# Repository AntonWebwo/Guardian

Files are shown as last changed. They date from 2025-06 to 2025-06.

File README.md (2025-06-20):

GUARDIAN

# Guardian - Пожарно-охранная система на Arduino

## Описание

Система Guardian – это пожарно-охранная система на базе Arduino, предназначенная для мониторинга состояния помещения и оповещения о возникновении нештатных ситуаций, таких как:

*   Открытие двери
*   Обнаружение движения
*   Задымление
*   Превышение уровня воды
*   Изменение температуры и влажности

## Функциональность

*   Поддержка до 3 зон (помещений)
*   Контроль открытия двери (геркон)
*   Обнаружение движения (PIR-датчики)
*   Обнаружение задымления (датчики дыма)
*   Контроль уровня воды (датчик уровня воды)
*   Мониторинг температуры и влажности (DHT22)
*   Постановка/снятие с охраны с помощью keypad
*   SMS-оповещения через GSM-модуль
*   Звуковые оповещения через DFPlayer Mini
*   Световая индикация режимов работы (светодиоды)
*   Управление реле (сирена, свет)
*   Настройка параметров через Serial Monitor

#### Система состоит из двух Arduino:

*  **Основная Arduino**: 
   Обрабатывает данные с вспомогательной Arduino, управляет логикой работы системы (постановка/снятие с охраны, сирена, реле), взаимодействует с пользователем через LCD-дисплей и keypad, отправляет SMS-оповещения через GSM-модуль и воспроизводит звуковые оповещения через DFPlayer Mini.

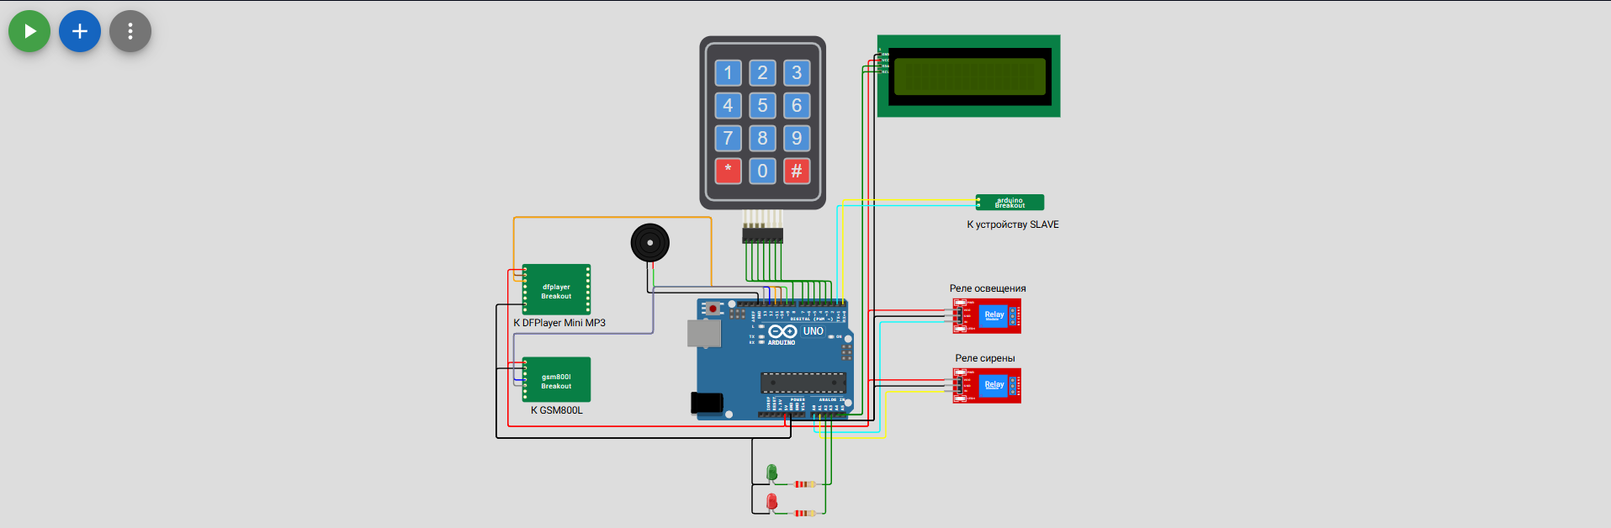
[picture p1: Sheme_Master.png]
Схема головного устройства


*  **Вспомогательная Arduino**: Собирает данные с датчиков (геркон, датчики дыма, датчики движения, датчик температуры и влажности DHT22, датчик уровня воды) и передает их на основную Arduino по последовательному порту.

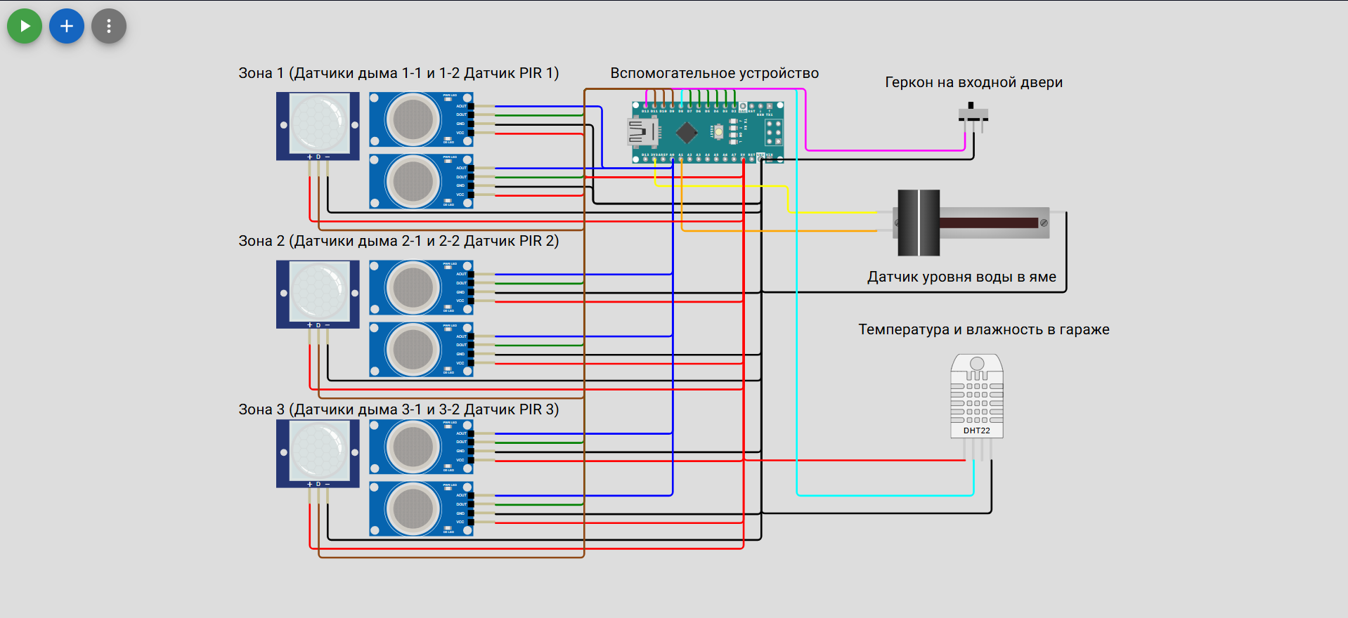
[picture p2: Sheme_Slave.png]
Схема вспомогательного устройства


## Схема подключения

### Основная Arduino
    
    +-------------------------+---------------------+
    | Компонент               | Пин Arduino         |
    +-------------------------+---------------------+
    | LCD-дисплей (SDA)       | A4                  |
    | LCD-дисплей (SCL)       | A5                  |
    | Keypad                  | 2, 3, 4, 5, 6, 7, 8 |
    | Реле света              | A0                  |
    | Реле сирены             | A1                  |
    | Красный светодиод       | A2                  |
    | Зеленый светодиод       | A3                  |
    | Буззер                  | 9                   |
    | DFPlayer Mini (RX)      | 11                  |
    | DFPlayer Mini (TX)      | 10                  |
    | GSM-модуль (RX)         | 13                  |
    | GSM-модуль (TX)         | 12                  |
    | Serial (Вспом. Arduino) | (RX, TX)            |
    +-------------------------+---------------------+

### Вспомогательная Arduino

    +---------------------------------------+-----------------------+
    | Компонент                             | Пин Arduino           |
    +---------------------------------------+-----------------------+
    | Датчик температуры/влажности (DHT22)  | 8                     |
    | Датчики дыма                          | A0 + 2, 3, 4, 5, 6, 7 |
    | Датчики движения (PIR)                | 9, 10, 11             |
    | Геркон                                | 12                    |
    | Датчик уровня воды                    | A1                    |
    | Serial (Основ. Arduino)               | (RX, TX)              |
    +---------------------------------------+-----------------------+

#### Протоколы и взаимодействие

1. **I2C**: Используется для связи основной Arduino с LCD-дисплеем. Адрес дисплея по умолчанию – 0x27.

2. **Последовательный порт (Serial)**:

   * Основная Arduino принимает данные от вспомогательной Arduino в следующем формате (Hex String):

            FF[GerconState][Sensor1][Sensor2][Sensor3][Sensor4][Sensor5][Sensor6][Motion1][Motion2][Motion3][TemperatureSign][Temperature][Humidity][WaterLevel]FF

      * FF: Start and End Byte
      * GerconState: 01 - дверь открыта, 00 - дверь закрыта
      * Sensor1-6: 01 - задымление, 00 - норма
      * Motion1-3: 01 - движение, 00 - нет движения
      * TemperatureSign: 00 - отрицательная температура, 01 - положительная температура
      * Temperature: Температура в градусах Цельсия (Hex)
      * Humidity: Влажность в процентах (Hex)
      * WaterLevel: 01 - высокий уровень воды, 00 - норма
      
        Примеры пакетов от вспомогательной Arduino:

      * `FF00000000000000000000010d4000FF` - Дверь закрыта. Дыма нет. Движения нет. Не затапливает. Температура 13.0°C. Влажность 64.5%.
      * `FF00000000000000000100010d4000FF` - Дверь закрыта. Дыма нет. Сработал датчик движения. Не затапливает. Температура 13.0°C. Влажность 64.5%.
      * `FF00000100000000000000010d4000FF` - Дверь закрыта. Сработал 1 датчик дыма. Движения нет. Не затапливает. Температура 13.0°C. Влажность 64.5%.
      * `FF00010100000000000000010d4000FF` - Дверь закрыта. Сработали 2 датчика дыма. Движения нет. Не затапливает. Температура 13.0°C. Влажность 64.5%.
      * `FF01000000000000000000010d4000FF` - Дверь открыта. Дыма нет. Движения нет. Не затапливает. Температура 13.0°C. Влажность 64.5%.
      * `FF00000000000000000000010d4001FF` - Дверь закрыта. Дыма нет. Движения нет. Затапливает. Температура 13.0°C. Влажность 64.5%.

    * Основная Arduino отправляет команды конфигурации на основную Arduino в формате:

    	* SET[variable]=[value] - установить значение переменной
    	* GET[variable] - получить значение переменной

3. **GSM (Serial)**: Основная Arduino использует AT-команды для отправки SMS-оповещений через GSM-модуль.
4. **DFPlayer Mini (Serial)**: Основная Arduino использует библиотеку `DFPlayer_Mini_Mp3.h` для воспроизведения звуковых оповещений.

#### Конфигурация

Параметры системы хранятся в EEPROM основной Arduino. Их можно изменить через Serial Monitor, отправляя команды `SET`.

   * `secretCode`: Код для снятия/постановки на охрану (4 цифры). По умолчанию "0000".
   * `phoneOperator`: Номер телефона оператора для отправки SMS (11 цифр). По умолчанию "89000000000".
   * `delay_lock`: Задержка перед постановкой на охрану (мс). По умолчанию 2500.
   * `delay_unlock`: Задержка перед снятием с охраны (мс). По умолчанию 500.
   * `delay_pass`: Задержка после ввода неверного пароля (мс). По умолчанию 1000.
   * `pass_timeout`: Время ожидания ввода пароля после открытия двери (мс). По умолчанию 30000.
   * `delay_siren`: Время работы сирены (мс). По умолчанию 30000.

Пример:

   * `SET secretCode=1234`
   * `SET phoneOperator=89123456789`
   * `GET info` - выводит текущие настройки в Serial Monitor
   * ~~`GET eeprom` - выводит дамп EEPROM в Serial Monitor~~

#### Логика работы

1. **Постановка на охрану**:
	* Пользователь нажимает кнопку # на клавиатуре.
	* Воспроизводится звуковое оповещение "Взятие под охрану. Покиньте объект!".
	* Моргает зеленый светодиод.
	* Идёт обратный отсчет **delay_lock**.
	* По окончанию **delay_lock** гаснет свет и подсветка на дисплее.
	* Воспроизводится звуковое оповещение "Объект установлен под охрану!".
	* Загорается красный светодиод.
	* Прибор переходит в режим охраны.
2. **Снятие с охраны**:
	* Пользователь открывает дверь (срабатывает геркон).
	* Включается свет и подсветка на дисплее.
	* Воспроизводится звуковое оповещение "Внимание! Дверь открыта. Введите пароль!".
	* Идёт обратный отсчет **pass_timeout**.
	* Если код верен, система снимается с охраны через **delay_unlock**.
		* Включается зеленый светодиод, выключается красный.
		* Воспроизводится звуковое оповещение "Внимание! Объект снят с охраны!".
	* Если код верен неправильный:
		* Продолжается отсчет **pass_timeout**.
		* Воспроизводится звуковое оповещение "Неправильный пароль! Повторите попытку!".
		* Идёт обратный отсчет **delay_pass**.
	* Если истекло время ввода правильного пароля:
		* Выключается свет и посветка на дисплее.
		* Воспроизводится звуковое оповещение "Тревога! Проникновение на объект!".
		* Включается сирена.
		* Идёт отправка SMS о событии.
3. **Тревога**:
	* При срабатывании датчиков (движение, задымление, превышение уровня воды) система отправляет SMS-оповещение на номер телефона оператора.
	* Включается сирена.
	* Воспроизводится соответствующее звуковое оповещение.
4. **Изменение код**а:
	* В режиме снятия с охраны пользователь нажимает кнопку "*".
	* Система предлагает ввести новый код и подтвердить его.
	* Если коды совпадают, новый код сохраняется в EEPROM.

#### Необходимые библиотеки

* Wire.h
* LiquidCrystal_I2C.h
* Keypad.h
* EEPROM.h
* SoftwareSerial.h
* DFPlayer_Mini_Mp3.h
* dht.h

#### Голосовое уведомление

Файлы Mp3 необходимо поместить в папку mp3 на sd карте в DFPlayer Mini. Библиотека *DFPlayer Mini Mp3* будет автоматически вызывать и проигрывать нужный трек при событиях.

#### Компоненты

* Прибор

    * Arduino UNO
	* Arduino Nano
	* Плата расширения IO Shield для Arduino Nano
	* Корпус пластиковый 120х100х40 мм для конструирования РЭА
	* Источник бесперебойного питания 12 В-2 А
	* Дисплей LCD1602C с I2C
	* [Накладка на дисплей](Models/Display_panel.stl)
	* Матричная клавиатура 3х4 механическая
	* Зуммер
	* Светодиодный модуль 0.23 Вт, Красный/Зелёный 
	* Модуль реле Ардуино, 2 канала, 220В 10А
	* Динамик YD103-71 6W 8ohm
	* Аудио модуль (MP3-плеер) DFPlayer mini
	* Модуль GPRS GSM SIM800l + антена

* Датчики и комплектующие

    * Датчик широкого спектра газов MQ-2 Arduino (6 ШТ)
	* [Корпус (низ) для MQ-2](Models/MQ2-Bottom-02.stl)
	* [Корпус (верх) для MQ-2](Models/MQ2-Top-02.stl)
    * Инфракрасный датчик движения HC-SR501 для Arduino (3 ШТ)
	* [Корпус для HC-SR501](Models/PIR45_angular.stl)
	* Проводной магнитоконтактный датчик (геркон) двери (1 ШТ)
	* Датчик уровня воды Ардуино (1 ШТ)
	* Цифровой датчик температуры и влажности DHT22 (AM2302) (1 ШТ)
	* Проводная свето-звуковая сирена к охранной сигнализации
	* Светодиодный модуль 0.23 Вт, Красный/Зелёный 

#### Информация

Попробовать в эмуляторе можно по ссылкам:

[Головное устройство](https://wokwi.com/projects/432747694750118913)
[Вспомогательное устройство](https://wokwi.com/projects/432639970081871873)

## Автор

[Антон Виноградов](https://t.me/vinantole)

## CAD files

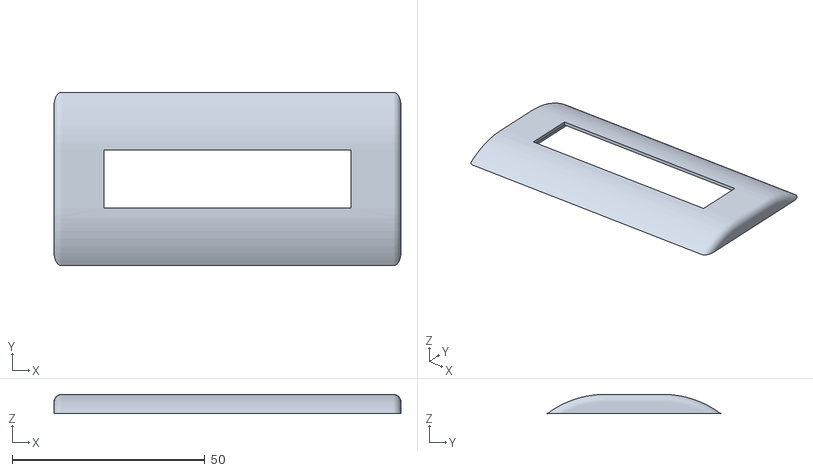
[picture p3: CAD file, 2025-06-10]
Models/Display_panel.stl
90.0 x 45.0 x 5.00

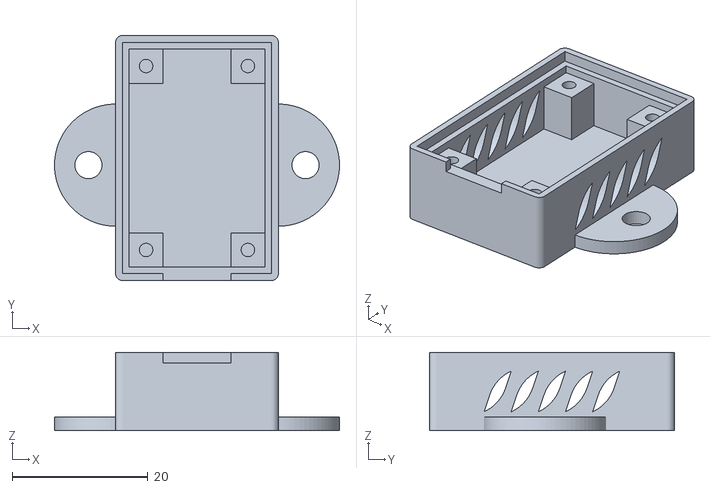
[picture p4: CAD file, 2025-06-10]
Models/MQ2-Bottom-02.stl
42.0 x 36.1 x 11.6

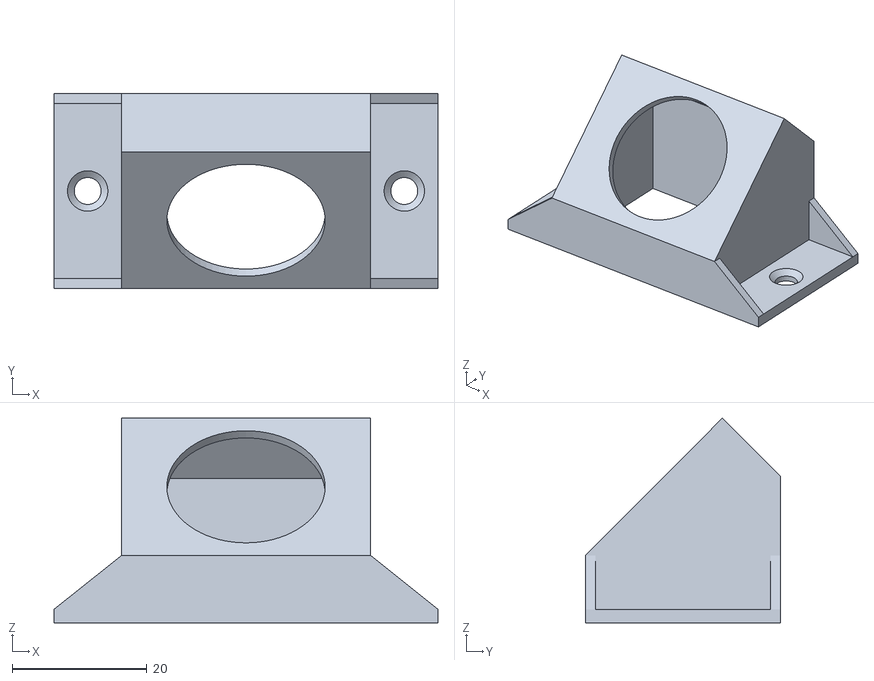
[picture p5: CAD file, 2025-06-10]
Models/PIR45_angular.stl
57.0 x 29.0 x 30.4

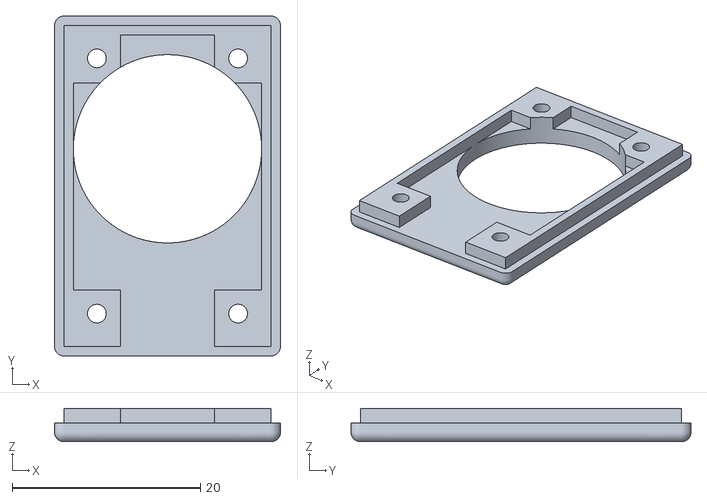
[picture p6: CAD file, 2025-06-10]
Models/MQ2-Top-02.stl
24.0 x 36.1 x 3.55

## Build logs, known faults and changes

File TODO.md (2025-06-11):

### Далее добавить

* Опрос состояния через SMS
* Пожарные события:
  * При сработке 1 датчика дыма: Предупреждение и SMS о событии.
  * При сработке 2 датчиков в одной зоне: Событие "Пожар" и SMS о событии.
* Имена зон в памяти устройства и отображение их при собвтии в SMS и на экране, например: *lobby -> motion detect!*
* Поддержка дополнительных вспомогательных устройств (Поддержка более 3 зон).
* Снятие / постановка при помощи RFID-модуля.
* Снятие / постановка через SMS.
* WEB приложение.

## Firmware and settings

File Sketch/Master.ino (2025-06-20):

#include <Wire.h>
#include <LiquidCrystal_I2C.h>
#include <Keypad.h>
#include <EEPROM.h>
#include <SoftwareSerial.h>
#include <DFPlayer_Mini_Mp3.h>

String version = "1.2.4"; // Версия прошивки

LiquidCrystal_I2C lcd(0x27, 16, 2);
uint8_t iconLocked[8] = {0x0e, 0x11, 0x11, 0x1f, 0x1b, 0x1b, 0x1f};
uint8_t iconUnlocked[8] = {0x0e, 0x10, 0x10, 0x1f, 0x1b, 0x1b, 0x1f};

char keys[4][3] = { { '1', '2', '3' }, { '4', '5', '6' }, { '7', '8', '9' }, { '*', '0', '#' } };
uint8_t colPins[3] = { 4, 3, 2 };
uint8_t rowPins[4] = { 8, 7, 6, 5 };
Keypad keypad = Keypad(makeKeymap(keys), rowPins, colPins, 4, 3);

char secretCode[5] = "";
char phoneOperator[12] = "";
int delay_lock, delay_unlock, delay_pass, pass_timeout, delay_siren;

char sensors[6][3];
char motion[3][3];
char gercoState[3];
char waterLevel[3];
int humidity, temperature;

int lastHumidity = -1;
int lastTemperature = -1;

bool Locked = true;
char enterCode[5] = "";
char newCode[5] = "";
char confirmCode[5] = "";

bool isDisplayed = false;
bool isNewCode = false;

unsigned long sirenStartTime = 0;
unsigned long lightStartTime = 0;

bool sirenActive = false;
bool lightActive = false;
bool alarmActive = false;

unsigned long alarmStartTime = 0;
const unsigned long alarmInterval = 500;
const unsigned long soundDuration = 300;

unsigned long lastWaterLevelAlertTime = 0;
const unsigned long waterLevelAlertInterval = 30 * 60 * 1000;

SoftwareSerial dfPlayerSerial(11, 10);
SoftwareSerial sim800l(13, 12);

void setup() {
    Serial.begin(115200);
    dfPlayerSerial.begin(9600);
    mp3_set_serial (dfPlayerSerial);
    mp3_set_volume (25);
    sim800l.begin(9600);
    sim800l.println("AT+CMGF=1");
    sim800l.println("AT+CNMI=2,2,0,0,0");
    loadSettings();
    lcd.begin(16, 2);
    lcd.createChar(1, iconLocked);
    lcd.createChar(2, iconUnlocked);
    lcd.noBacklight();
    pinMode(A2, OUTPUT);
    pinMode(A3, OUTPUT);
    pinMode(A0, OUTPUT);
    pinMode(A1, OUTPUT);
    pinMode(9, OUTPUT);
    digitalWrite(A2, HIGH);
    digitalWrite(A3, LOW);
    digitalWrite(A0, LOW);
    digitalWrite(A1, LOW);
    showStartupMessage();
}

void loop() {
    static unsigned long previousMillis = 0;
    const long interval = 100;

    unsigned long currentMillis = millis();
    if (currentMillis - previousMillis >= interval) {
        previousMillis = currentMillis;
        getSerialData();
        if (Locked) {
            checkSiren();
            monitorAlarmSystem();
            safeLockedLogic();
        } else {
            lcd.backlight();
            safeUnlockedLogic();
        }
        checkAlarm();
    }
}

void loadSettings() {
    bool settingsChanged = false;

    EEPROM.get(0, secretCode);
    EEPROM.get(16, phoneOperator);
    EEPROM.get(32, delay_lock);
    EEPROM.get(48, delay_unlock);
    EEPROM.get(64, delay_pass);
    EEPROM.get(80, pass_timeout);
    EEPROM.get(96, delay_siren);

    if (strlen(secretCode) != 4 || strspn(secretCode, "0123456789") != 4) {
        strcpy(secretCode, "0000");
        writeStringToEEPROM(0, secretCode);
        settingsChanged = true;
    }

    if (strlen(phoneOperator) != 11 || strspn(phoneOperator, "0123456789") != 11) {
        strcpy(phoneOperator, "89000000000");
        writeStringToEEPROM(16, phoneOperator);
        settingsChanged = true;
    }

    if (delay_lock <= 0) {
        delay_lock = 2500;
        EEPROM.put(32, delay_lock);
        settingsChanged = true;
    }

    if (delay_unlock <= 0) {
        delay_unlock = 500;
        EEPROM.put(48, delay_unlock);
        settingsChanged = true;
    }

    if (delay_pass <= 0) {
        delay_pass = 1000;
        EEPROM.put(64, delay_pass);
        settingsChanged = true;
    }

    if (pass_timeout <= 0) {
        pass_timeout = 30000;
        EEPROM.put(80, pass_timeout);
        settingsChanged = true;
    }

    if (delay_siren <= 0) {
        delay_siren = 30000;
        EEPROM.put(96, delay_siren);
        settingsChanged = true;
    }

    if (settingsChanged) {
        handleGetCommand("GET info");
    }
}


void writeStringToEEPROM(int address, const char* str) {
    for (int i = 0; i < strlen(str); i++) {
        EEPROM.write(address + i, str[i]);
    }
    EEPROM.write(address + strlen(str), '\0');
}

void showStartupMessage() {
    lcd.backlight();
    lcd.setCursor(4, 0);
    lcd.print("Welcome!");
    delay(1000);
    lcd.setCursor(0, 1);
    lcd.write(1);
    String message = "Guardian v" + version;
    for (char c : message) {
        lcd.print(c);
        controlBuzzer(true, 5);
        delay(95);
    }
    delay(500);
    lcd.noBacklight();
}

void getSerialData() { 

    /* События при входящих SMS */
    // if (sim800l.available()) {
    //     String inputSMS = sim800l.readStringUntil('\n'); // Читаем первую строку
    //     String secondLine = sim800l.readStringUntil('\n'); // Читаем вторую строку
    //     String thirdLine = sim800l.readStringUntil('\n'); // Читаем третью строку

    //     Serial.println(thirdLine); // Выводим третью строку

    //     if (thirdLine.startsWith("UNLOCK")) {
    //         showUnlockMessage();
    //     }
    // }

    if (Serial.available() > 0) {
        String inputData = Serial.readStringUntil('\n');
        inputData.trim();

        if (inputData.startsWith("SET")) {
            handleSetCommand(inputData);
        } else if (inputData.startsWith("GET")) {
            handleGetCommand(inputData);
        } else {
            gercoState[0] = inputData[2];
            gercoState[1] = inputData[3];
            gercoState[2] = '\0';
            for (int i = 0; i < 6; i++) {
                sensors[i][0] = inputData[4 + i * 2];
                sensors[i][1] = inputData[5 + i * 2];
                sensors[i][2] = '\0';
            }
            for (int i = 0; i < 3; i++) {
                motion[i][0] = inputData[16 + i * 2];
                motion[i][1] = inputData[17 + i * 2];
                motion[i][2] = '\0';
            }
            humidity = strtol(inputData.substring(26, 28).c_str(), NULL, 16);
            temperature = strtol(inputData.substring(24, 26).c_str(), NULL, 16);
            if (inputData[23] != '1') temperature = -temperature;
            waterLevel[0] = inputData[28];
            waterLevel[1] = inputData[29];
            waterLevel[2] = '\0';
        }
    }
}

void handleSetCommand(const String& inputData) {
    int equalIndex = inputData.indexOf('=');
    if (equalIndex > 0) {
        String variableName = inputData.substring(4, equalIndex);
        String value = inputData.substring(equalIndex + 1);
        variableName.trim();
        value.trim();
        
        if (variableName == "secretCode") {
            value.toCharArray(secretCode, sizeof(secretCode));
            writeStringToEEPROM(0, secretCode);
        } else if (variableName == "phoneOperator") {
            value.toCharArray(phoneOperator, sizeof(phoneOperator));
            writeStringToEEPROM(16, phoneOperator);
        } else if (variableName == "delay_lock") {
            delay_lock = value.toInt();
            EEPROM.put(32, delay_lock);
        } else if (variableName == "delay_unlock") {
            delay_unlock = value.toInt();
            EEPROM.put(48, delay_unlock);
        } else if (variableName == "delay_pass") {
            delay_pass = value.toInt();
            EEPROM.put(64, delay_pass);
        } else if (variableName == "pass_timeout") {
            pass_timeout = value.toInt();
            EEPROM.put(80, pass_timeout);
        } else if (variableName == "delay_siren") {
            delay_siren = value.toInt();
            EEPROM.put(96, delay_siren);
        } 

        Serial.println("Write to EEPROM: " + variableName + " = " + value);
    } 
}

void handleGetCommand(const String& inputData) {
    String variableName = inputData.substring(4);
    if (variableName == "info") {
        Serial.println("delay_lock: " + String(delay_lock));
        Serial.println("delay_unlock: " + String(delay_unlock));
        Serial.println("delay_pass: " + String(delay_pass));
        Serial.println("pass_timeout: " + String(pass_timeout));
        Serial.println("delay_siren: " + String(delay_siren));
        Serial.println("secretCode: " + String(secretCode));
        Serial.println("phoneOperator: " + String(phoneOperator));
    }
}

void displayTemperature() {
    lcd.setCursor(0, 0);
    lcd.print("TEMP:           ");
    lcd.setCursor(5, 0);
    lcd.print("T:");
    lcd.print(temperature);
    lcd.print(" H:");
    lcd.print(humidity);
}

void safeUnlockedLogic() {
    if (!isDisplayed) {
        lcd.clear();
        lcd.setCursor(0, 1);
        lcd.print("PRESS # TO LOCK");
        isDisplayed = true;
    }

    if (humidity != lastHumidity || temperature != lastTemperature) {
        displayTemperature();
        lastHumidity = humidity;
        lastTemperature = temperature;
    }

    char key = keypad.getKey();
    if (key) {
        if (key == '#') {
            lockSystem();
        } else if (key == '*') {
            enterNewCode();
        }
    }
}

void lockSystem() {
    mp3_play(1); //Взятие под охрану. Покиньте объект!
    lcd.clear();
    lcd.setCursor(4, 0);
    lcd.write(2);
    lcd.print(" ");
    for (int i = 0; i < 4; i++) lcd.write(126);
    lcd.print(" ");
    lcd.write(1);
    Locked = true;
    isDisplayed = false;
    showWaitScreen(delay_lock, A3);
    digitalWrite(A2, HIGH);
    digitalWrite(A3, LOW);
}

void enterNewCode() {
    lcd.clear();
    lcd.setCursor(0, 0);
    lcd.print("Enter new code:");
    lcd.setCursor(5, 1);
    lcd.print("[____]");
    lcd.setCursor(6, 1);
    newCode[0] = '\0';
    isNewCode = true;

    while (isNewCode) {
        char key = keypad.getKey();
        if (key >= '0' && key <= '9' && strlen(newCode) < 4) {
            lcd.print(key);
            strncat(newCode, &key, 1);
            controlBuzzer(true, 25);
            if (strlen(newCode) == 4) {
                lcd.clear();
                lcd.setCursor(0, 0);
                lcd.print("Confirm code:");
                lcd.setCursor(5, 1);
                lcd.print("[____]");
                lcd.setCursor(6, 1);
                confirmCode[0] = '\0';
                isNewCode = false;
            }
        }
    }
    confirmNewCode();
}

void confirmNewCode() {
    while (strlen(confirmCode) < 4) {
        char key = keypad.getKey();
        if (key >= '0' && key <= '9') {
            lcd.print(key);
            strncat(confirmCode, &key, 1);
            controlBuzzer(true, 25);
            if (strlen(confirmCode) == 4) {
                if (strcmp(newCode, confirmCode) == 0) {
                    strcpy(secretCode, newCode);
                    writeStringToEEPROM(0, secretCode);
                    lcd.clear();
                    lcd.setCursor(0, 0);
                    lcd.write(1);
                    lcd.print(" NEW CODE: ");
                    lcd.print(secretCode);
                    digitalWrite(A3, HIGH);
                    delay(1000);
                    lastHumidity = -1;
                    lastTemperature = -1;
                } else {
                    lcd.clear();
                    lcd.setCursor(0, 0);
                    lcd.print("PASSWORDS ERROR!");
                    delay(1000);
                }
                newCode[0] = '\0';
                confirmCode[0] = '\0';
                isDisplayed = false;
                return;
            }
        }
    }
}

void safeLockedLogic() {
    static bool isVerifying = false;

    if (!isDisplayed) {
        lcd.noBacklight();
        digitalWrite(A0, LOW);
        mp3_play(2); //Объект установлен под охрану!
        lcd.clear();
        lcd.setCursor(0, 0);
        lcd.write(1);
        lcd.print("  ENTER CODE  ");
        lcd.write(1);
        lcd.setCursor(5, 1);
        lcd.print("[____]");
        lcd.setCursor(6, 1);
        isDisplayed = true;
        for (byte i = 0; i < 5; i++) {
            controlBuzzer(true, 100);
            delay(50);
        }
    }

    if (strlen(enterCode) < 4 && !isVerifying) {
        char key = keypad.getKey();
        if (key >= '0' && key <= '9') {
            lcd.print('*');
            strncat(enterCode, &key, 1);
            controlBuzzer(true, 25);
        }
    } else {
        isVerifying = true;
        showWaitScreen(delay_unlock, 12);
        if (strcmp(secretCode, enterCode) == 0) {
            digitalWrite(A1, LOW);
            digitalWrite(A0, LOW);
            sirenActive = false;
            lightActive = false;
            showUnlockMessage();
            enterCode[0] = '\0';
            Locked = false;
            digitalWrite(A3, HIGH);
            digitalWrite(A2, LOW);
        } else {
            mp3_play(3); //Неправильный пароль! Повторите попытку.
            enterCode[0] = '\0';
            lcd.clear();
            lcd.setCursor(0, 0);
            lcd.write(1);
            lcd.print(" ACCESS DENIED!");
            lcd.setCursor(6, 1);
            showWaitScreen(delay_pass, 12);
            digitalWrite(A3, LOW);
            digitalWrite(A2, HIGH);
            for (byte i = 0; i < 5; i++) {
                controlBuzzer(true, 250);
                delay(250);
            }
        }
        isDisplayed = false;
        isVerifying = false;
    }
}

void showWaitScreen(int delayMillis, int ledPin) {
    lcd.setCursor(2, 1);
    lcd.print("[..........]");
    lcd.setCursor(3, 1);
    for (byte i = 0; i < 10; i++) {
        digitalWrite(ledPin, (i % 2 == 0) ? HIGH : LOW);
        controlBuzzer(true, 50);
        delay(delayMillis);
        lcd.print("=");
    }
    digitalWrite(ledPin, LOW);
}

void showUnlockMessage() {
    deactivateAlarm();
    mp3_play(4); //Внимание! Объект снят с охраны!
    digitalWrite(A1, LOW);
    digitalWrite(A0, HIGH);
    sirenActive = false;
    lightActive = false;
    lastHumidity = -1;
    lastTemperature = -1;
    lcd.clear();
    lcd.setCursor(0, 0);
    lcd.write(2);
    lcd.print("   UNLOCKED!  ");
    lcd.write(2);
    for (byte i = 0; i < 5; i++) {
        controlBuzzer(true, 100);
        delay(50);
    }
    delay(1000);
}

void sendAlert(const char* message) {
    lcd.setCursor(0, 0);
    lcd.print(message);
    lcd.setCursor(6, 1);
    SendSMS(phoneOperator, message);
    
}

void monitorAlarmSystem() {
    if (Locked) {
        if (strcmp(gercoState, "01") == 0 && !lightActive) {
            sendAlert("! Door is open !");
            mp3_play(5); //Внимание! Дверь открыта. Введите пароль.
            digitalWrite(A0, HIGH);
            lightStartTime = millis();
            lightActive = true;
            lcd.backlight();
            for (byte i = 0; i < 5; i++) {
                controlBuzzer(true, 250);
                delay(250);
            }
        }

        if (lightActive && (millis() - lightStartTime >= pass_timeout)) {
            sendAlert("!!!PASS ALARM!!!");
            mp3_play(6); // Тревога! Проникновение на объект!
            digitalWrite(A0, LOW);
            lightActive = false;
            activateSiren();
            lcd.noBacklight();
        }

        for (int i = 0; i < 3; i++) {
            if (strcmp(motion[i], "01") ==  0 && !sirenActive) {
                sendAlert("!!MOTION ALARM!!");
                mp3_play(7); // Тревога! Обнаружено движение!
                activateSiren();
                sirenActive = true;
                sirenStartTime = millis();
            }
        }

        int activeSensors = 0;
        for (int i = 0; i < 6; i++) {
            if (strcmp(sensors[i], "01") == 0) {
                activeSensors++;
            }
        }

        if (activeSensors >= 2 && !sirenActive) {
            sendAlert("!!!FIRE ALARM!!!");
            mp3_play(8); // Тревога! Задымление помещения!
            activateSiren();
            sirenActive = true;
            sirenStartTime = millis();
        } else if (activeSensors < 2) {
            activeSensors = 0;
        }

        if (strcmp(waterLevel, "01") == 0) {
            unsigned long currentTime = millis();
            if (currentTime - lastWaterLevelAlertTime >= waterLevelAlertInterval) {
                sendAlert("! WATER LEVEL !");
                mp3_play(9); // Внимание! Высокий уровень воды!
                controlBuzzer(true, 250);
                lastWaterLevelAlertTime = currentTime;
            }
        }
    } else {
        lightActive = false;
        lcd.noBacklight();
    }
}

void activateSiren() {
    if (!sirenActive) {
        activateAlarm();
        digitalWrite(A1, HIGH);
        sirenStartTime = millis();
        sirenActive = true;
    }
}

void checkSiren() {
    if (sirenActive && (millis() - sirenStartTime >= delay_siren)) {
        digitalWrite(A1, LOW);
        deactivateAlarm();
        sirenActive = false;
    }
}

void controlBuzzer(bool turnOn, int soundDur) {
    if (turnOn) {
        digitalWrite(9, HIGH);
        delay(soundDur);
        digitalWrite(9, LOW);
    } else {
        digitalWrite(9, LOW);
    }
}

void activateAlarm() {
    alarmActive = true;
    alarmStartTime = millis();
}

void deactivateAlarm() {
    alarmActive = false;
    digitalWrite(9, LOW);
}

void checkAlarm() {
    if (alarmActive) {
        unsigned long currentMillis = millis();
        
        if (currentMillis - alarmStartTime >= alarmInterval) {

            if (digitalRead(9) == LOW) {
                digitalWrite(9, HIGH);
            } else {
                digitalWrite(9, LOW);
            }
            alarmStartTime = currentMillis;
        }
    }
}

void SendSMS(const char* phone, String message) {
  sim800l.print("AT+CMGS=\"");
  sim800l.print(phone);
  sim800l.print("\"\r");
  delay(300);
  sim800l.print(message);
  delay(300);
  sim800l.print((char)26);
  delay(300);
  sim800l.println();
}

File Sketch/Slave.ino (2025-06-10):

#include <dht.h>

dht DHT;
#define DHT22_PIN 8
#define WATER_SENSOR_PIN A1

struct {
    uint32_t total, ok, crc_error, time_out, connect, ack_l, ack_h, unknown;
} stat = {0};

#define NUM_SENSORS 6
#define NUM_PIR_SENSORS 3

const int sensorPins[NUM_SENSORS] = {2, 3, 4, 5, 6, 7};
const int pirPins[NUM_PIR_SENSORS] = {9, 10, 11};

byte sensorValues[NUM_SENSORS];
byte pirValues[NUM_PIR_SENSORS];
int waterSensorValue;

const int gercoPin = 12;
int oldValue = HIGH;

void setup() {
    Serial.begin(115200);
    pinMode(gercoPin, INPUT_PULLUP);
    for (int i = 0; i < NUM_SENSORS; i++) {
        pinMode(sensorPins[i], INPUT);
    }
    for (int i = 0; i < NUM_PIR_SENSORS; i++) {
        pinMode(pirPins[i], INPUT);
    }
}

void loop() {
    checkButtonState();
    readSmokeSensors();
    readPirSensors();
    readDHTSensor();
    readWaterSensor();
    sendDataAsHexString();
    delay(1000);
}

void checkButtonState() {
    int newValue = digitalRead(gercoPin);
    if (newValue != oldValue) {
        oldValue = newValue;
    }
}

void readSmokeSensors() {
    for (int i = 0; i < NUM_SENSORS; i++) {
        sensorValues[i] = (digitalRead(sensorPins[i]) == LOW) ? 1 : 0;
    }
}

void readPirSensors() {
    for (int i = 0; i < NUM_PIR_SENSORS; i++) {
        pirValues[i] = (digitalRead(pirPins[i]) == HIGH) ? 1 : 0;
    }
}

void readDHTSensor() {
    int chk = DHT.read22(DHT22_PIN);
    stat.total++;
    switch (chk) {
        case DHTLIB_OK: stat.ok++; break;
        case DHTLIB_ERROR_CHECKSUM: stat.crc_error++; break;
        case DHTLIB_ERROR_TIMEOUT: stat.time_out++; break;
        case DHTLIB_ERROR_CONNECT: stat.connect++; break;
        case DHTLIB_ERROR_ACK_L: stat.ack_l++; break;
        case DHTLIB_ERROR_ACK_H: stat.ack_h++; break;
        default: stat.unknown++; break;
    }
}

void readWaterSensor() {
    waterSensorValue = analogRead(WATER_SENSOR_PIN);
}

void sendDataAsHexString() {
    String data = "FF";
    data += (oldValue == LOW) ? "01" : "00";

    for (int i = 0; i < NUM_SENSORS; i++) {
        data += (sensorValues[i] == 1) ? "01" : "00";
    }

    for (int i = 0; i < NUM_PIR_SENSORS; i++) {
        data += (pirValues[i] == 1) ? "01" : "00";
    }

    int temperature = static_cast<int>(DHT.temperature);
    String tempHex;
    data += (temperature < 0) ? "00" : "01";

    if (temperature < 0) {
        tempHex = String(abs(temperature), HEX);
    } else {
        tempHex = String(temperature, HEX);
    }

    if (tempHex.length() < 2) tempHex = "0" + tempHex;
    data += tempHex;

    int humidity = static_cast<int>(DHT.humidity);
    String humidityHex = String(humidity, HEX);
    if (humidityHex.length() < 2) humidityHex = "0" + humidityHex;
    data += humidityHex;

    data += (waterSensorValue < 500) ? "00" : "01";
    data += "FF";

    Serial.println(data);
}

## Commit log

2025-06-10 Create mp3
    Директория для sd карты
2025-06-20 Update Master.ino
    Оптимизация глобальных переменных.
